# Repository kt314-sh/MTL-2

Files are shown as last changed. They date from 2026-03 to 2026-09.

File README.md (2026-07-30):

<div align="center">
<h1>📡 MTL-2: Portable High-Power LoRa node</h1>
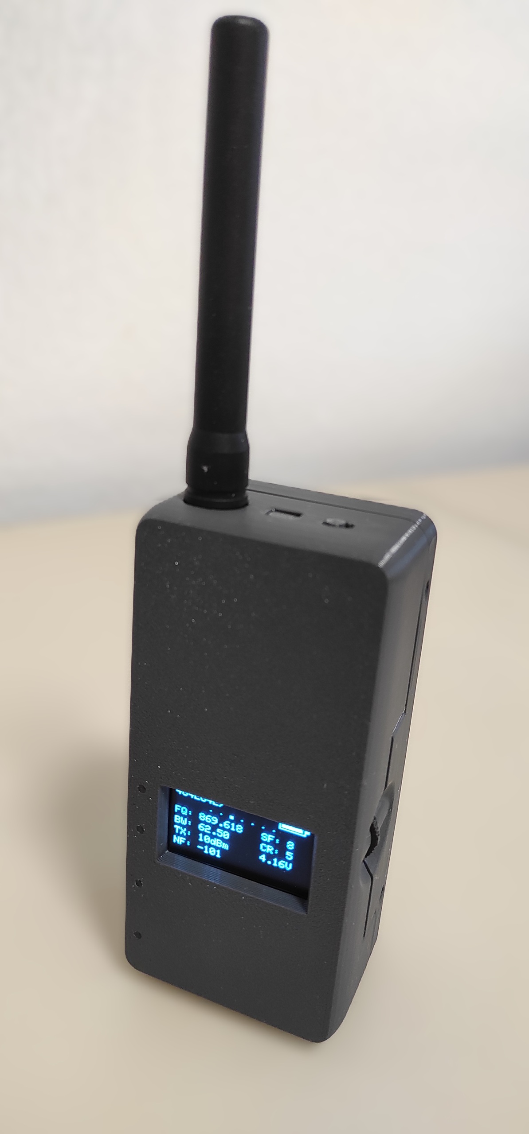
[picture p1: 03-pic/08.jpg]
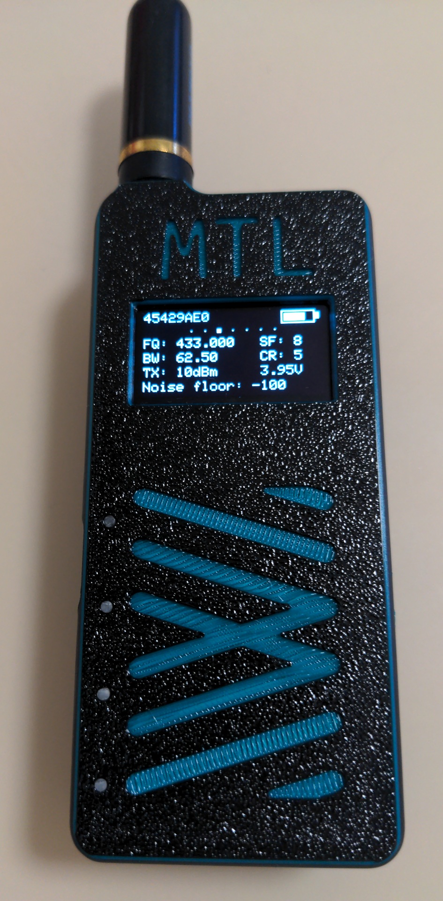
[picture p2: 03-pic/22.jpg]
   

<div align="left">
  
  ## MTL-2
MTL-2 - Это портативное энергоэкономичное устройство, основанное на модулях [Ebyete](https://www.ebyte.com/) и ProMicro (NRF52840). Предназначено для работы в [MeshCore](https://github.com/meshcore-dev), [Meshtastic](https://github.com/meshtastic), в качестве клиента и ретранслятора.

##  Ключевые особенности
* LoRa 30-31dBm
* Oled 1.3'
* Buzzer
* Switch Buzzer/Led (Quiet mode)
* Switch POWER set Low/Hight (20dBm/30dBm)
* Vibro-notification
* 3-position multifuctional switch or 3 button
* Connector for GPS-module like VK2828U7G5LF
* 1A Standalone Linear Li-Ion Battery Charger
* Battery protection lithium-ion/polymer battery
* Li-Ion cell holder 2x18650 TBH-18650-2A-P (FC1-5212)

##  Органы управления
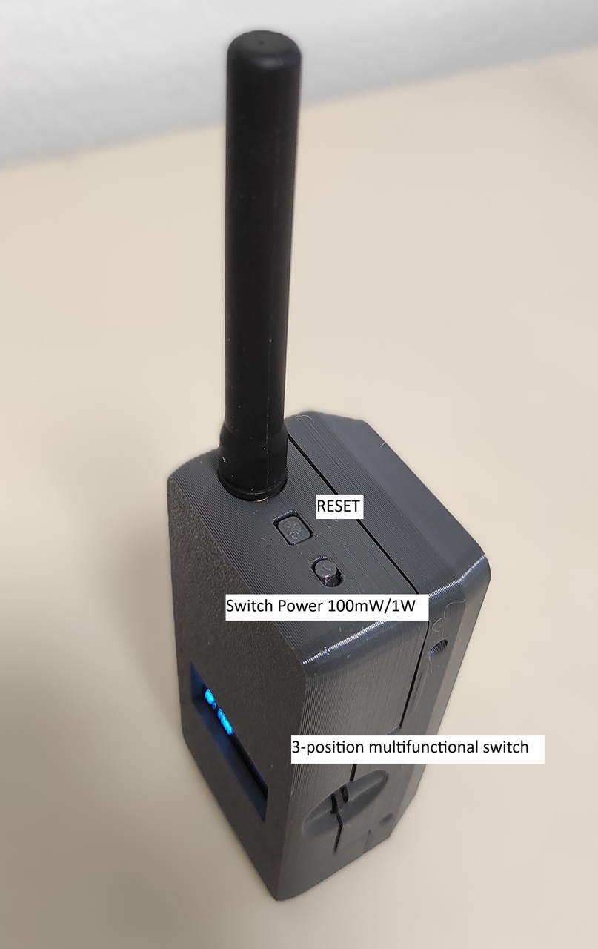
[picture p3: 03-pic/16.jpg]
interface1
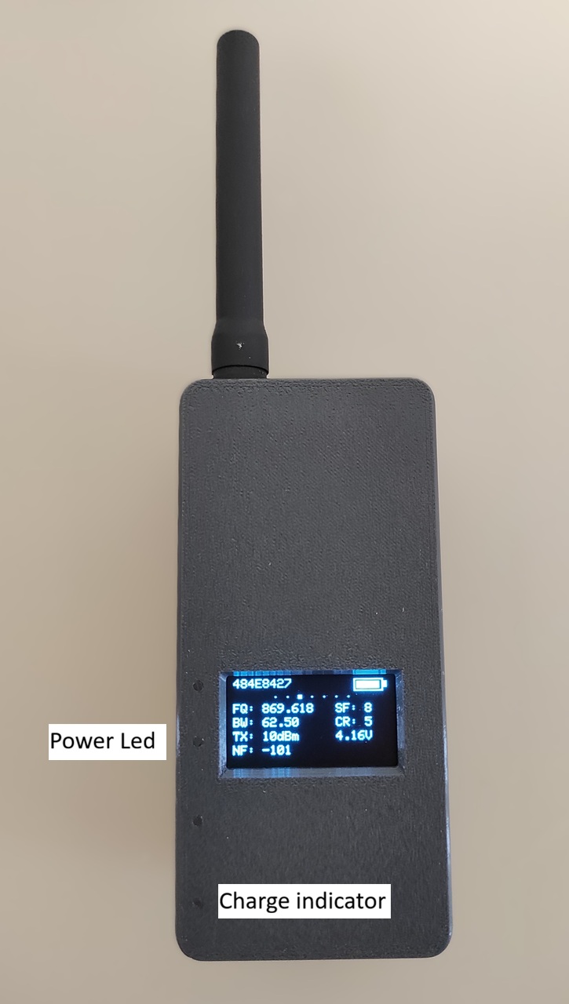
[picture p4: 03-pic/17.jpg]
interface2
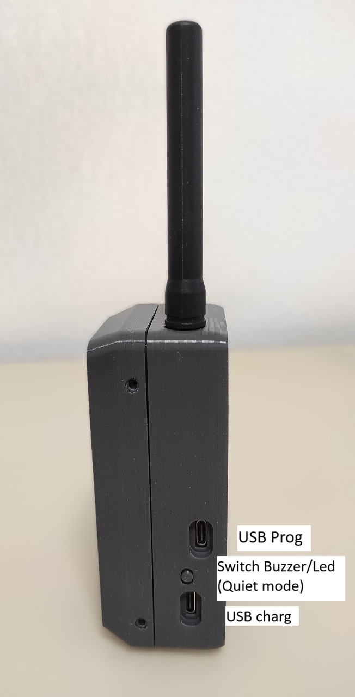
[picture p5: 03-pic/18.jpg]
interface3


##  Software MeshCore
The software was developed by [VladelfPv](https://github.com/VladelfPv)  [MTLmicro](https://github.com/VladelfPv/MeshCoreMTL.git) 

##  Software Meshtastic
Use the J9 jumper for compatibility with FakeTec. In this case, DC-DC Up remains constantly on, which will increase battery consumption to 10mA.

As a jumper, you can use the chip ferrite beads like BLM21PG221SN1D, BLM21PG121SH1D etc 
Оther settings are configured in the Meshtastic software.

GPIO: 
- 6-Buzzer.
- 8-Vibro.

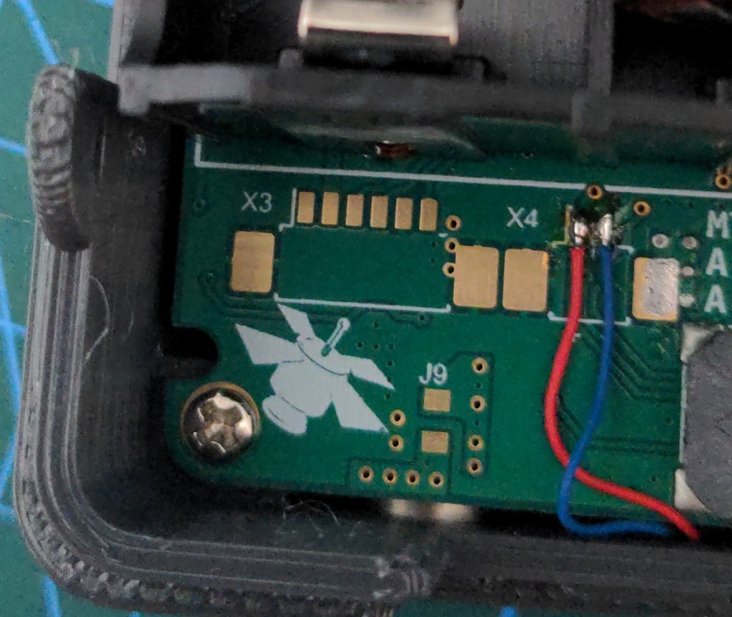
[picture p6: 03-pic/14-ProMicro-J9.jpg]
FakeTec
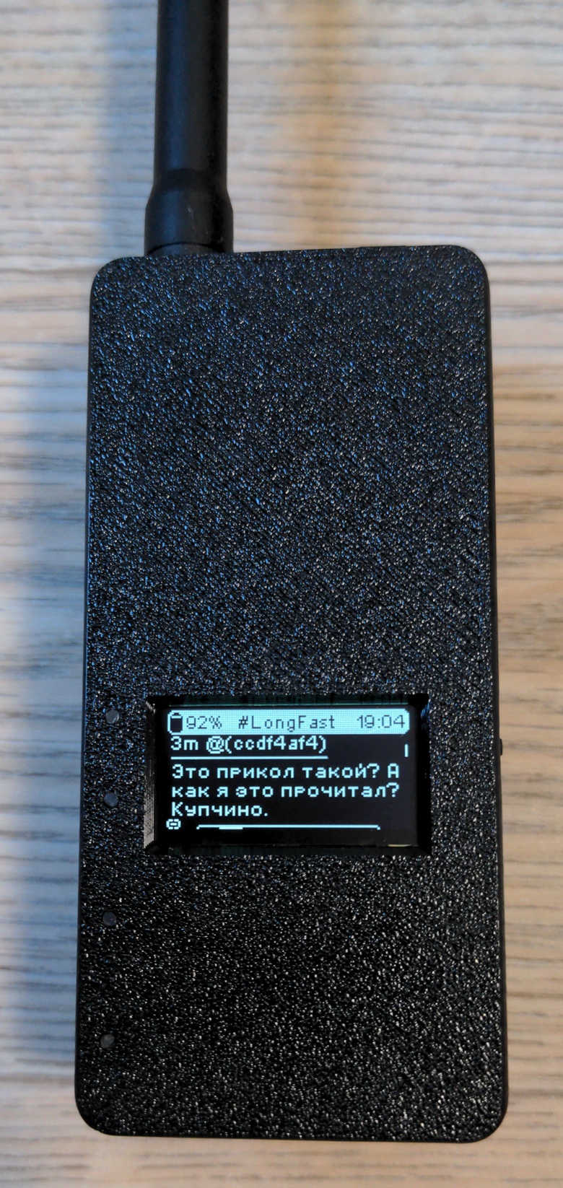
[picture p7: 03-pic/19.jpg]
FakeTec2


##  Update Software 
To update the Software, click the RESET button twice. In the window that opens, copy the firmware file xxxxx.uf2

interface1

### Frequency range
#### 150-170Mhz
- e22-170m30s    SX1268  30dBm

#### 430Mhz
- e22p-433m30s   SX1268          30dBm
- e22-400m30s    SX1262, SX1268  30dBm 
- e22-400m33s    SX1268          33dBm
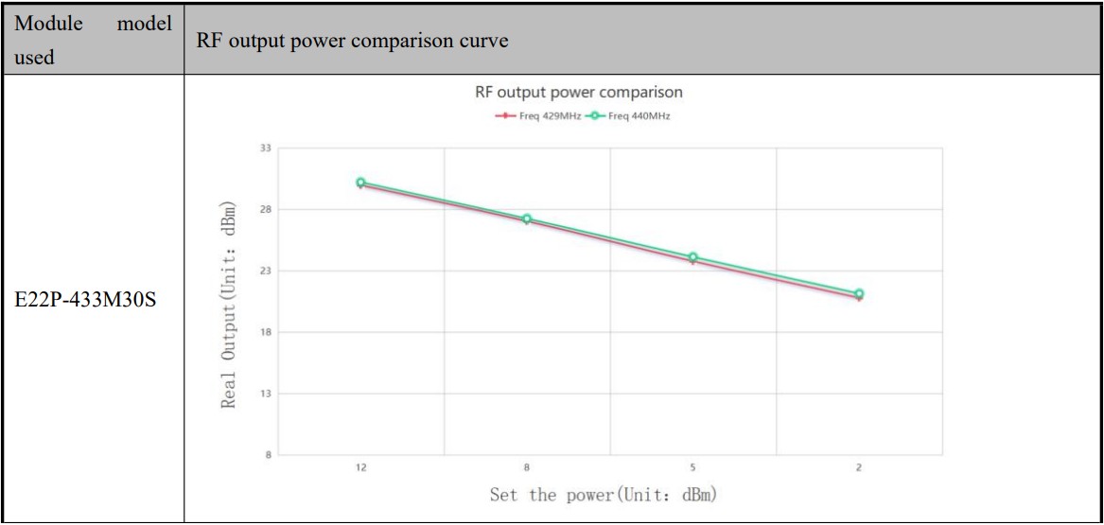
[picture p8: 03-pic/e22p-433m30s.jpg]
mtle22p433


#### 868-915Mhz
- e22p-868m30s   SX1262  31dBm
- e22p-915m30s   SX1262  31dBm 
- e22-900m30s    SX1262  30dBm
- e22-900m33s    SX1262  33dBm

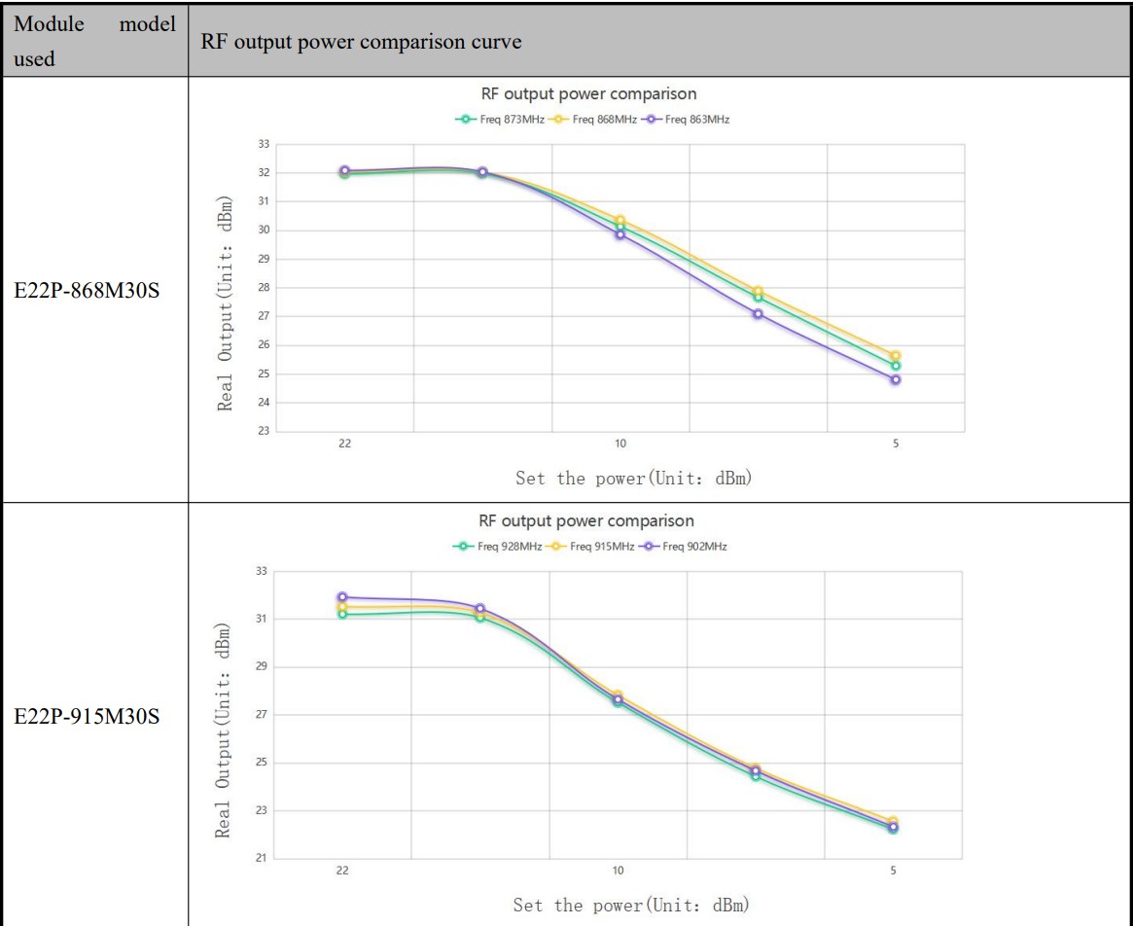
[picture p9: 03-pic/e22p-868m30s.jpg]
mtle22p868


##  Files
*[Gerber and Pick Place](/01-PCB/Fabrication)

*Shematic and documentation for [E22](/01-PCB/e22-C)

*Shematic and documentation for [E22p](/01-PCB/e22p-C)

*[IO spreadsheet](/01-PCB/MTL-2_IO.xlsx)

*3d model PCB [step](/04-3dmod)

*3d print model [Case](/05-case)

##  ⚠️Special attention
 Replace the capacitor C6 with a jumper!

##  Additional images

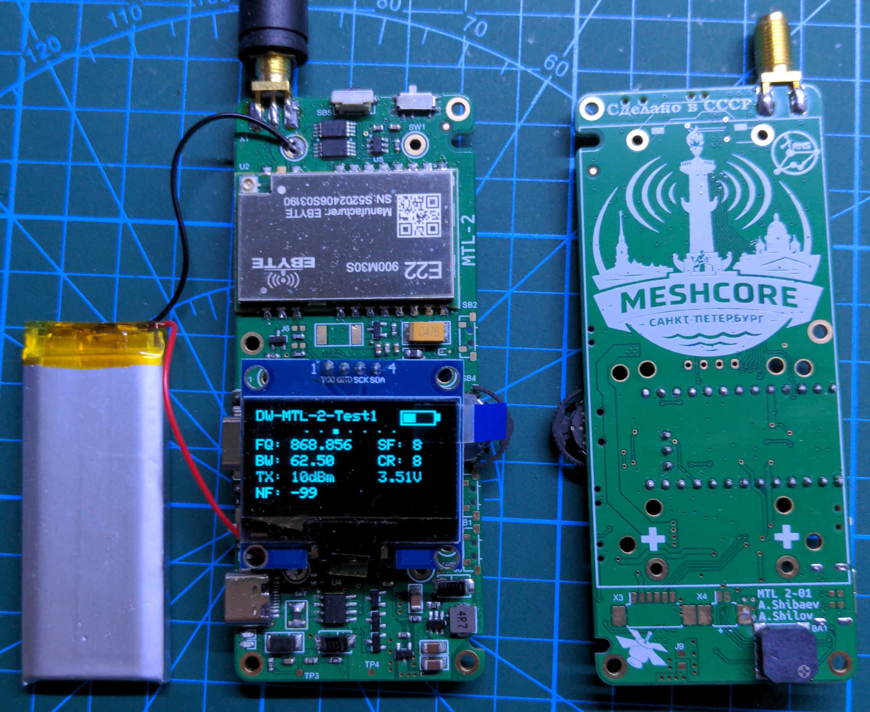
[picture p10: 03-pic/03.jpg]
Main
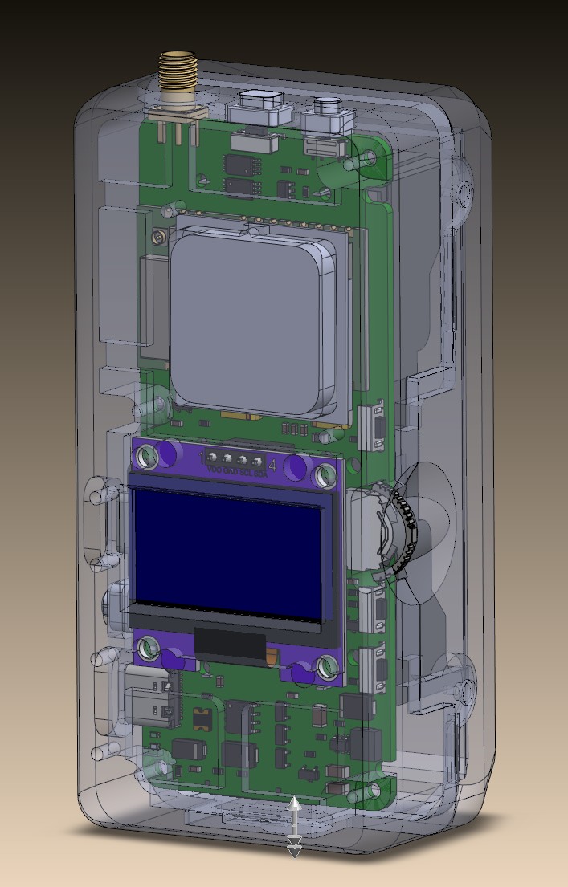
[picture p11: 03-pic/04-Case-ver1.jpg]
3dCaseF
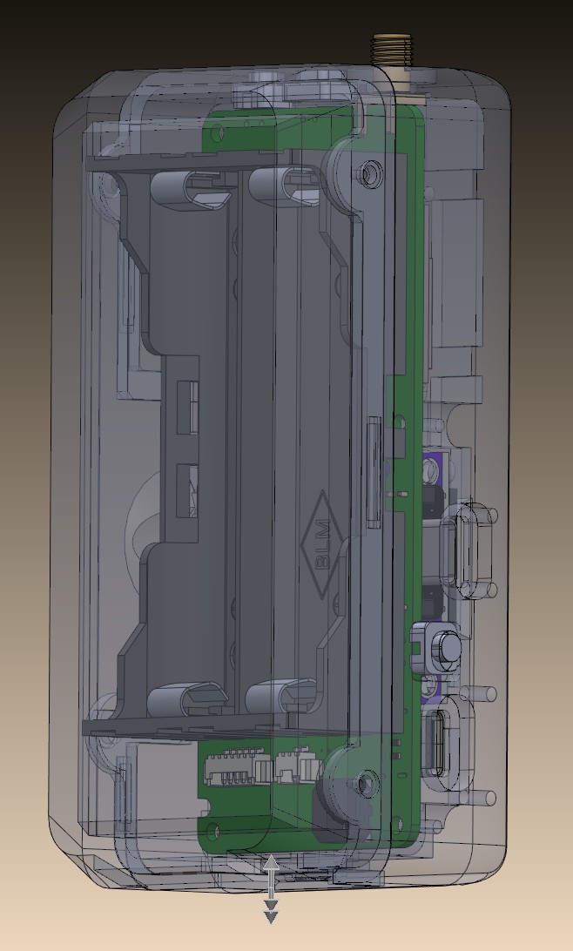
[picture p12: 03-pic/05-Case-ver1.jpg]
3dCaseB
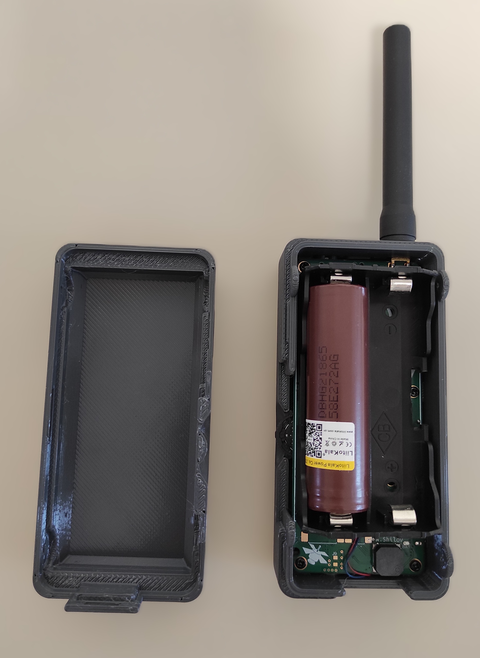
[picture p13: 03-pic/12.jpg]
back
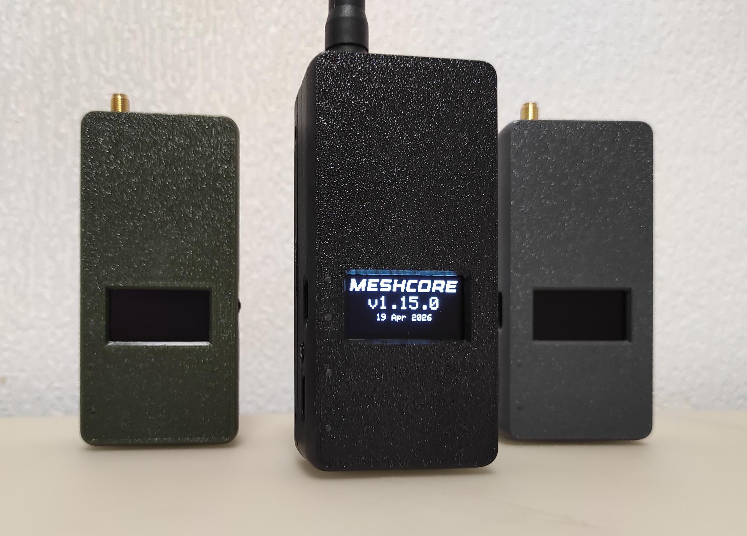
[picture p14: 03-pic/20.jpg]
case
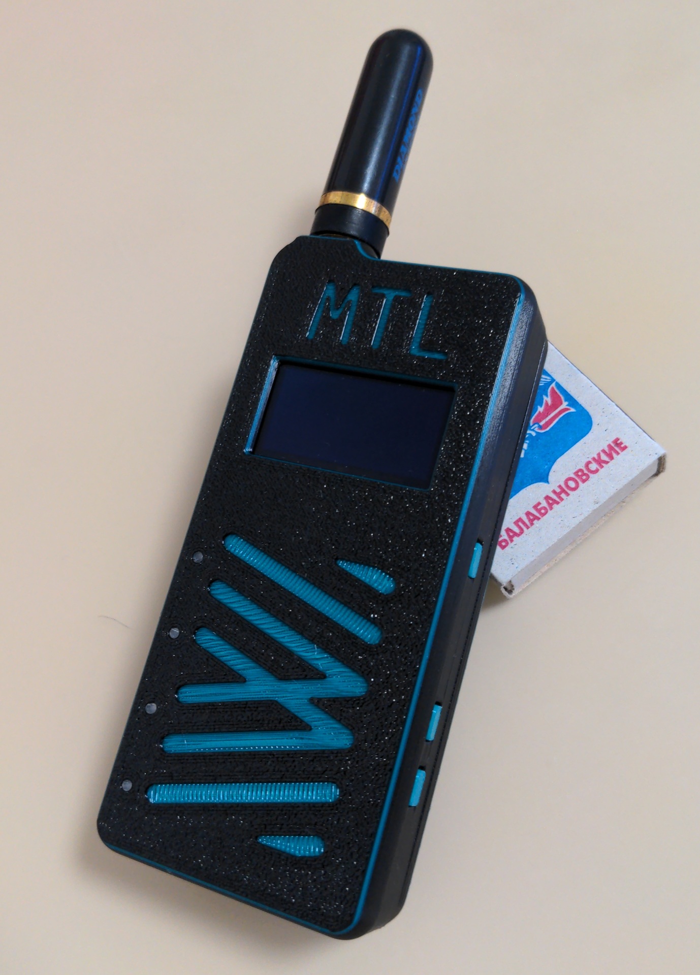
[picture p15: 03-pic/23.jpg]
 PCB

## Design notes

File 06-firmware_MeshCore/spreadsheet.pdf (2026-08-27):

| E22_sx1262_repeater.uf2
| E22_sx1262_SSD1306_repeater.uf2
E22p_sx1268_repeater.uf2
E22p_sx1268_SSD1306_repeater.uf2
| Файл прош+вк+ | Модуль LoRa | Д+сплей
SX1262 | SX1268 | Oled 1.3' | Oled 0.96'
E22-900m30s, E22-400m30s, E22-170m30s | E22p-868m30s, E22p-915m30s | E22-400m33s, E22-170m30s | E22p-430m30s, | SH1106 | SSD1306
| E22_sx1262_companion_radio_usb.uf2
| E22_sx1262_companion_radio_ble.uf2
| E22_sx1262_SSD1306_companion_radio_ble.uf2
| E22p_sx1268_companion_radio_usb.uf2
| E22p_sx1268_companion_radio_ble.uf2
| E22p_sx1268_SSD1306_companion_radio_usb.uf2
| E22p_sx1268_SSD1306_companion_radio_ble.uf2

Реп+тер,

мост UART

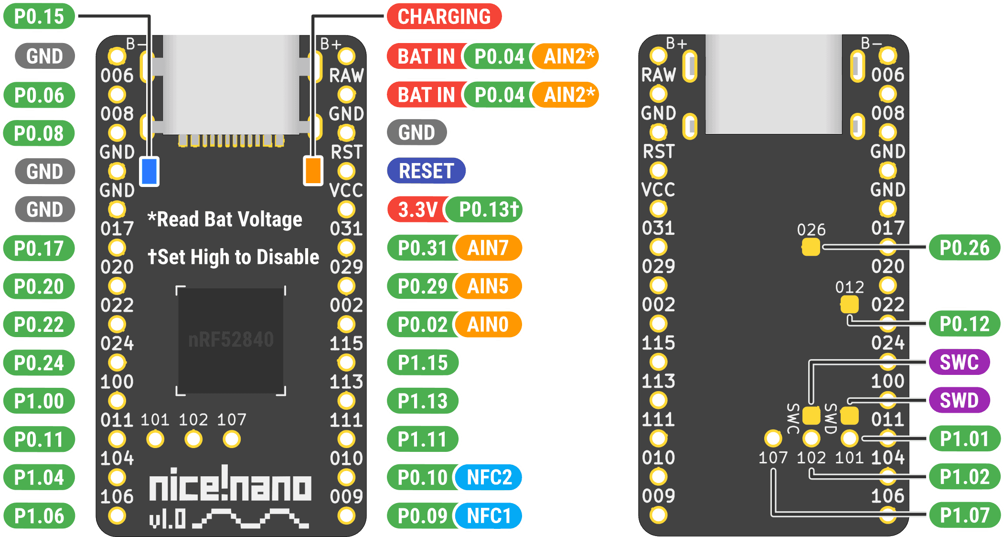
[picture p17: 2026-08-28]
02-datasheet/NiceNano_v1_pinout.png

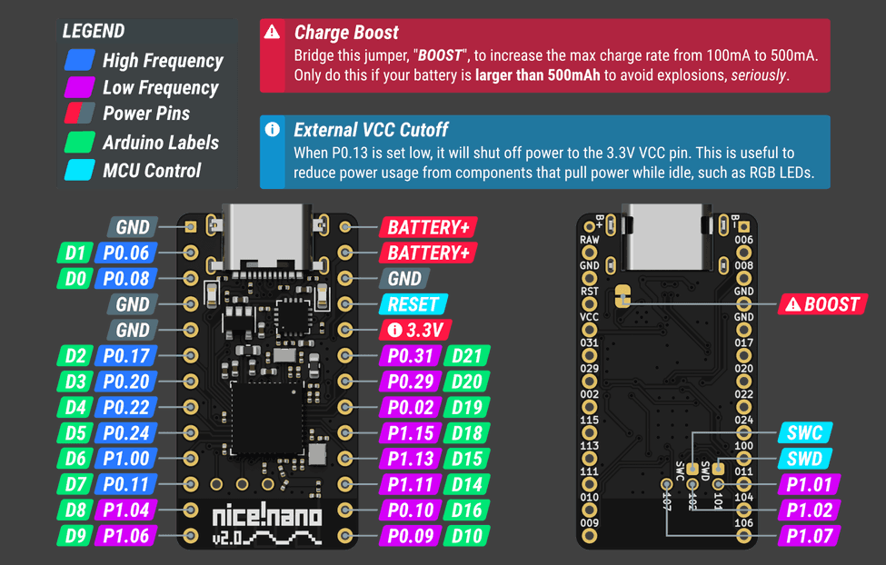
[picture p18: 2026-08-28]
02-datasheet/NiceNano_v2_pinout.png

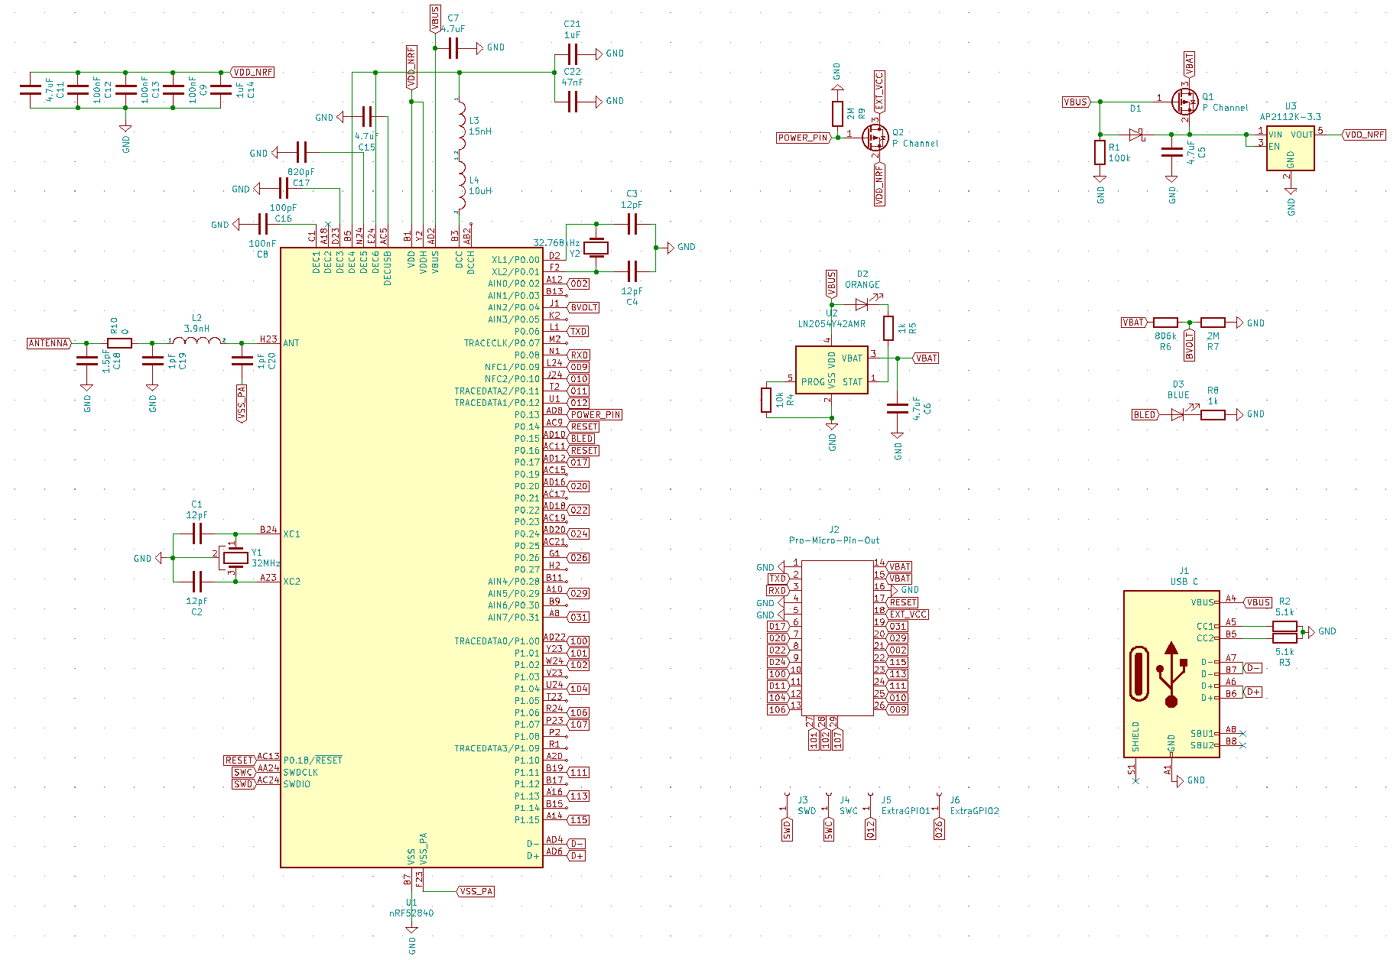
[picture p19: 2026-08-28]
02-datasheet/NiceNano_v1_schematic.png

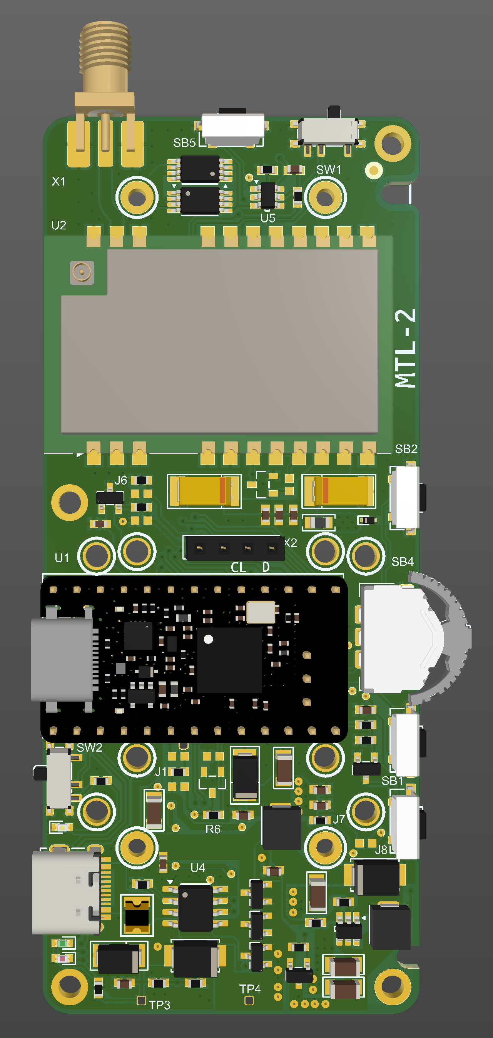
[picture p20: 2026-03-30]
03-pic/e22p-1.png

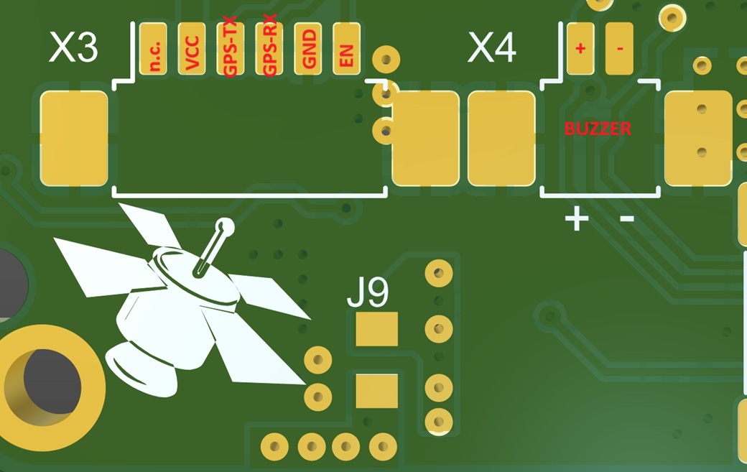
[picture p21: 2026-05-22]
03-pic/21-UART.jpg

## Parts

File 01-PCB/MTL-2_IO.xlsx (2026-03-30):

Port | GPIO | D Arduino | Net |  | Описание
P0.02 | 15 | 19 | MISO |  | LoRA
P0.06 | 0 | 1 | DO_BUZZ | PWM | Пассивный Зуммер EN=H
P0.08 | 1 | 0 | DO_VIBR | DO | Вибромотор, EN=H
P0.09 | 10 | 10 | NRST |  | LoRA
P0.10 | 11 | 16 | DIO1 |  | LoRA
P0.11 | 7 | 7 | i2c_SCL | I2C | Oled
P0.13 | 21 |  |  | DO | Включить питание 3.3В (дисплей, GPS, вибро) (нет необходимости отключать???)
P0.15 | 22 | 13 |  | DO | Led Красный
P0.17 | 2 | 2 | RX_EN | DO | Резерв, не используем, Модуль E22 активируем RX, Модуль E22p пробуждаем модуль (см. Datasheet)
P0.20 | 3 | 3 | GPS_RX | UART | Для GPS приемника VK2828U7G5LF
P0.22 | 4 | 4 | GPS_TX | UART | Для GPS приемника VK2828U7G5LF
P0.24 | 5 | 5 | GPS_EN | DO | Для GPS приемника пробуждение H, EN=H
P0.29 | 16 | 20 | BUSY |  | LoRA
P0.31 | 17 | 21 | ADC | AI | Измерение напряжения АКБ, коэффициент 1.47 (делитель 1МОм/680к)
P1.00 | 6 | 6 | SET_S | DI | Кнопка центральная, основная. Pull UP
P1.01 | 18 |  | SET_A | DI | Кнопка вверх. Pull UP
P1.02 | 19 |  | SET_B | DI | Кнопка вниз. Pull UP
P1.04 | 8 | 8 | i2c_SDA | I2C | Oled 1306
P1.06 | 9 | 9 | DC_EN | DO | Включить питание 5В. Модуль LoRa, GPS. EN=H
P1.07 | 20 |  | SET_PVR | DI | Переключатель ползунковый, для переключения мощности L/H. Например 20dBm/30dBm, либо одно значение берётся из переменной настроек приложения, второе максимальное значение (в настройках для модуля E22 20dBm=30dBm на выходе)
P1.11 | 12 | 14 | SCK |  | LoRA
P1.13 | 13 | 15 | NSS |  | LoRA
P1.15 | 14 | 18 | MOSI |  | LoRA

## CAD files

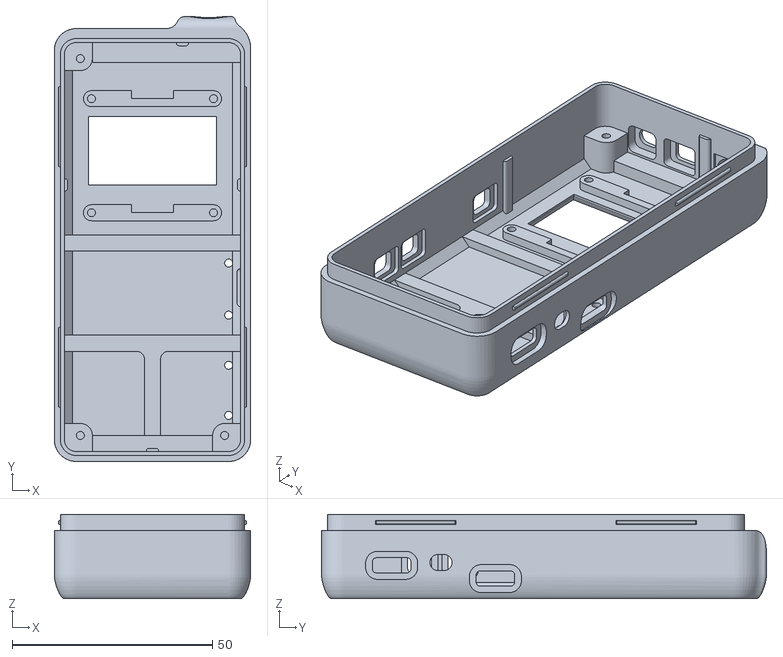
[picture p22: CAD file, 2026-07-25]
05-case/ver2/3d-Print/main21.07.2026.STL
49.0 x 111.0 x 21.0

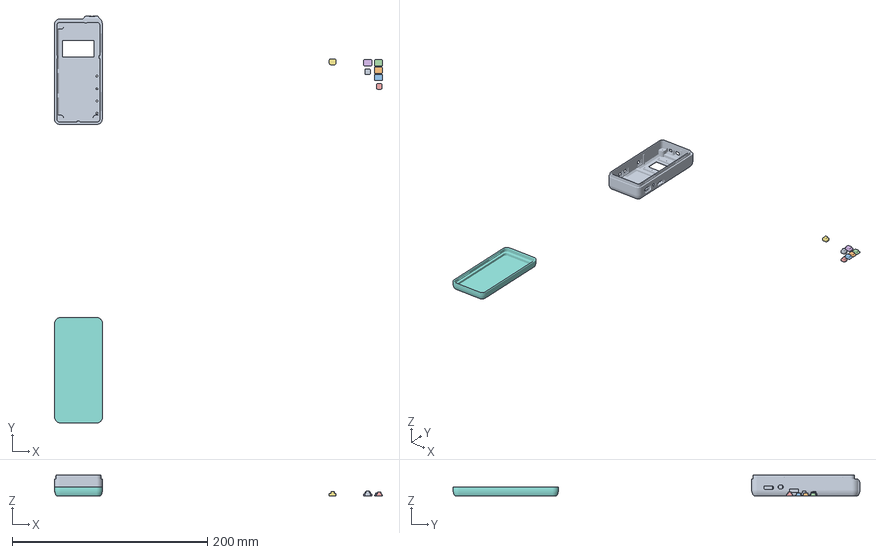
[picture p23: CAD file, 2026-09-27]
05-case/ver2/3d-Print/MTL-2v2.3mf
336.0 x 416.7 x 21.0 mm
main21.07.2026.STL
BT2-L.STL x 3
SW2.STL
BT1-L.STL
SW1.STL
Back-104060.STL
SW1-2.STL

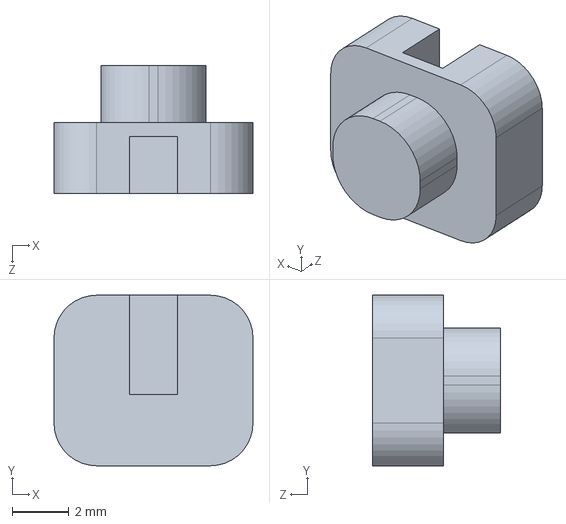
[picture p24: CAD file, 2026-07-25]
05-case/ver2/SolidWork/SW1.SLDPRT
7.00 x 6.00 x 4.50 mm

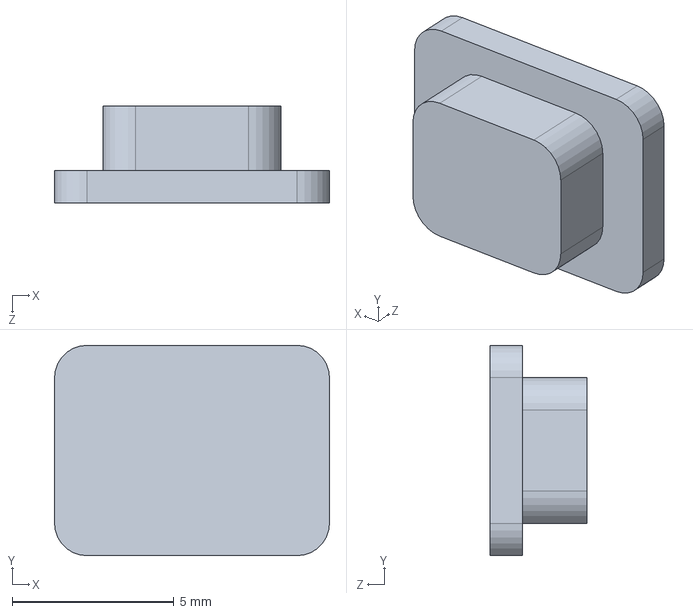
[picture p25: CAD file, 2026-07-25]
05-case/ver2/SolidWork/BT2-L.SLDPRT
8.50 x 6.50 x 3.00 mm

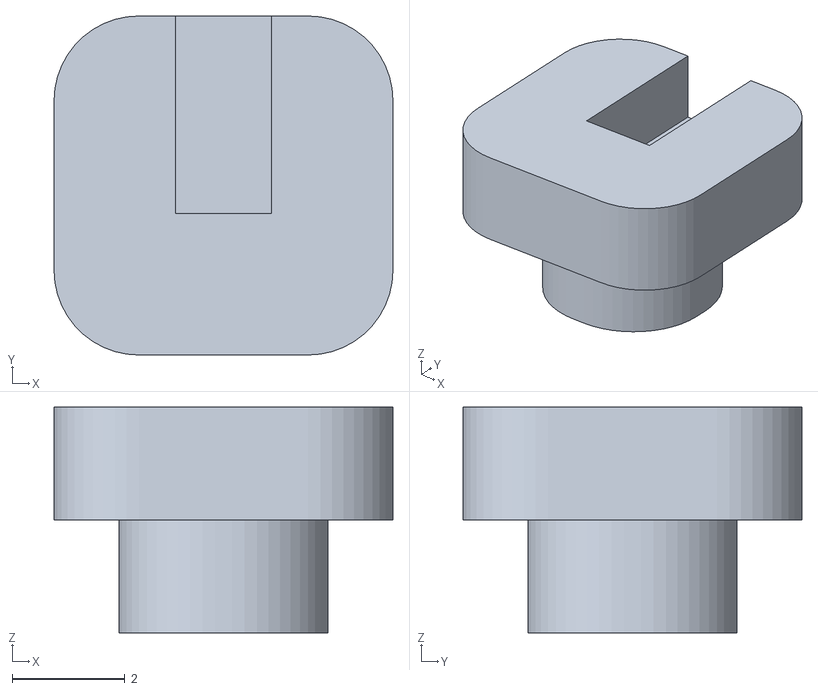
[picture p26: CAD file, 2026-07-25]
05-case/ver2/3d-Print/SW2.STL
6.00 x 6.00 x 4.00

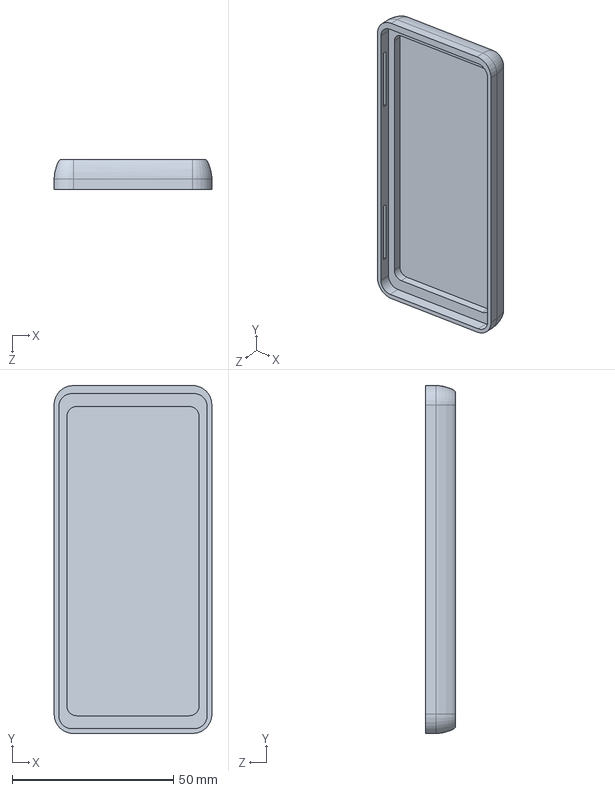
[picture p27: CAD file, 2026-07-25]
05-case/ver2/SolidWork/back1.SLDPRT
49.0 x 108.0 x 9.20 mm

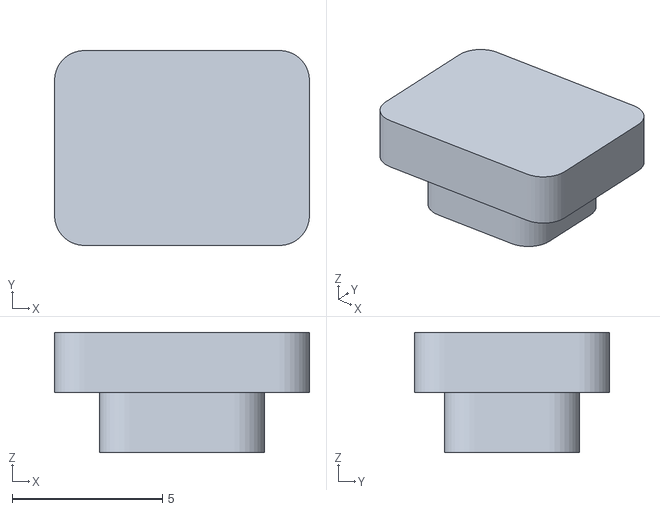
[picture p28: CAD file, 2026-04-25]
05-case/ver2/3d-Print/BT1-L.STL
8.50 x 6.50 x 4.00

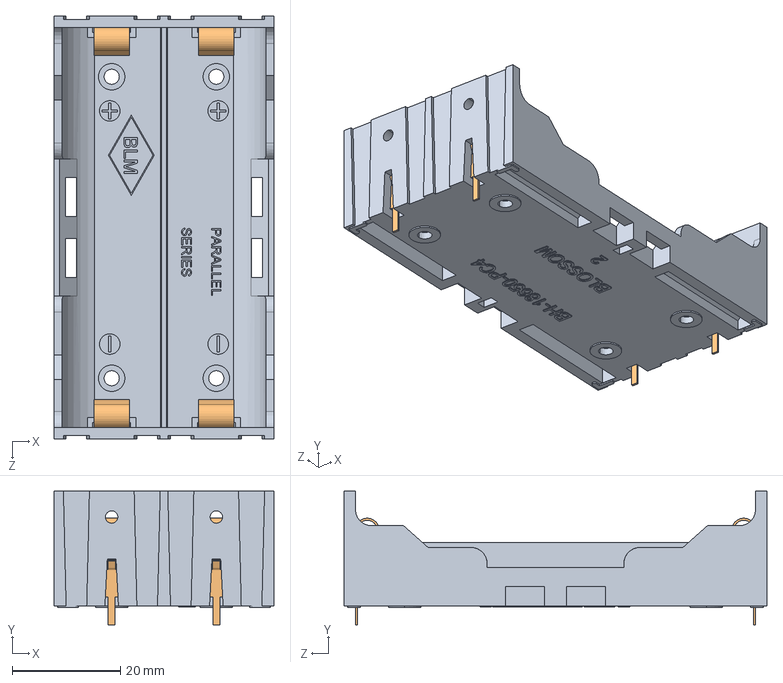
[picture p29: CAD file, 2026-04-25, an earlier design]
05-case/ver1/SolidWork/BC-18650-PC4.SLDASM
40.5 x 24.7 x 78.0 mm
____________2^__________ ____________________________ BC-18650-PC4_____ __________________.STEP.STEP
____________3^__________ ____________________________ BC-18650-PC4_____ __________________.STEP.STEP x 4

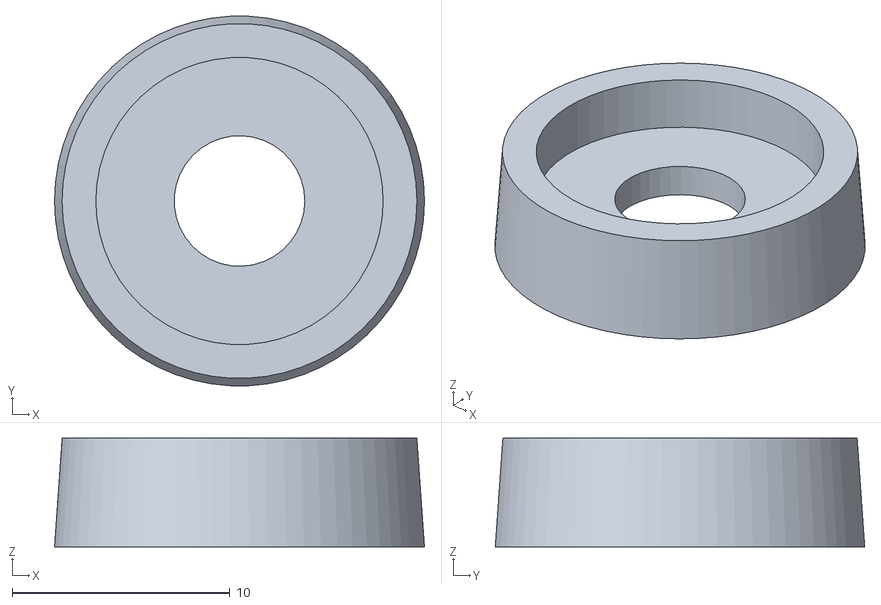
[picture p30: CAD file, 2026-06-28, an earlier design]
05-case/ver1/3d-Print/Ant-Holder/SONGKL-868.STL
17.0 x 17.0 x 5.00

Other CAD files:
05-case/ver2/SolidWork/main21.07.2026cp.SLDPRT
05-case/ver2/SolidWork/SW2.SLDPRT
05-case/ver2/3d-Print/BT2-L.STL
05-case/ver2/3d-Print/SW1.STL
05-case/ver2/3d-Print/Back-104060.STL
05-case/ver2/SolidWork/BT1-L.SLDPRT
05-case/ver2/SolidWork/18650.SLDPRT
05-case/ver2/3d-Print/18650.STL
05-case/ver2/SolidWork/104060.SLDPRT
05-case/ver1/3d-Print/Ant-Holder/All_TPU-95.3mf
05-case/ver1/3d-Print/Ant-Holder/GIZONT_GT-7702-20.STL
05-case/ver1/3d-Print/Ant-Holder/GIZONT_LORA-868.STL
05-case/ver1/3d-Print/Ant-Holder/RE-771.STL
05-case/ver1/3d-Print/Ant-Holder/TYT_TH-UV99.STL
05-case/ver1/3d-Print/BT1-L.3mf
05-case/ver1/3d-Print/Back.3mf
05-case/ver1/3d-Print/Back.STL
05-case/ver1/3d-Print/Bat-1.3mf
05-case/ver1/3d-Print/Bat-1.STL
05-case/ver1/3d-Print/Middle.3mf
05-case/ver1/3d-Print/Middle.STL
05-case/ver1/3d-Print/SW1-2.3mf
05-case/ver1/3d-Print/SW1-2.STL
05-case/ver1/3d-Print/SW1-3.3mf
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

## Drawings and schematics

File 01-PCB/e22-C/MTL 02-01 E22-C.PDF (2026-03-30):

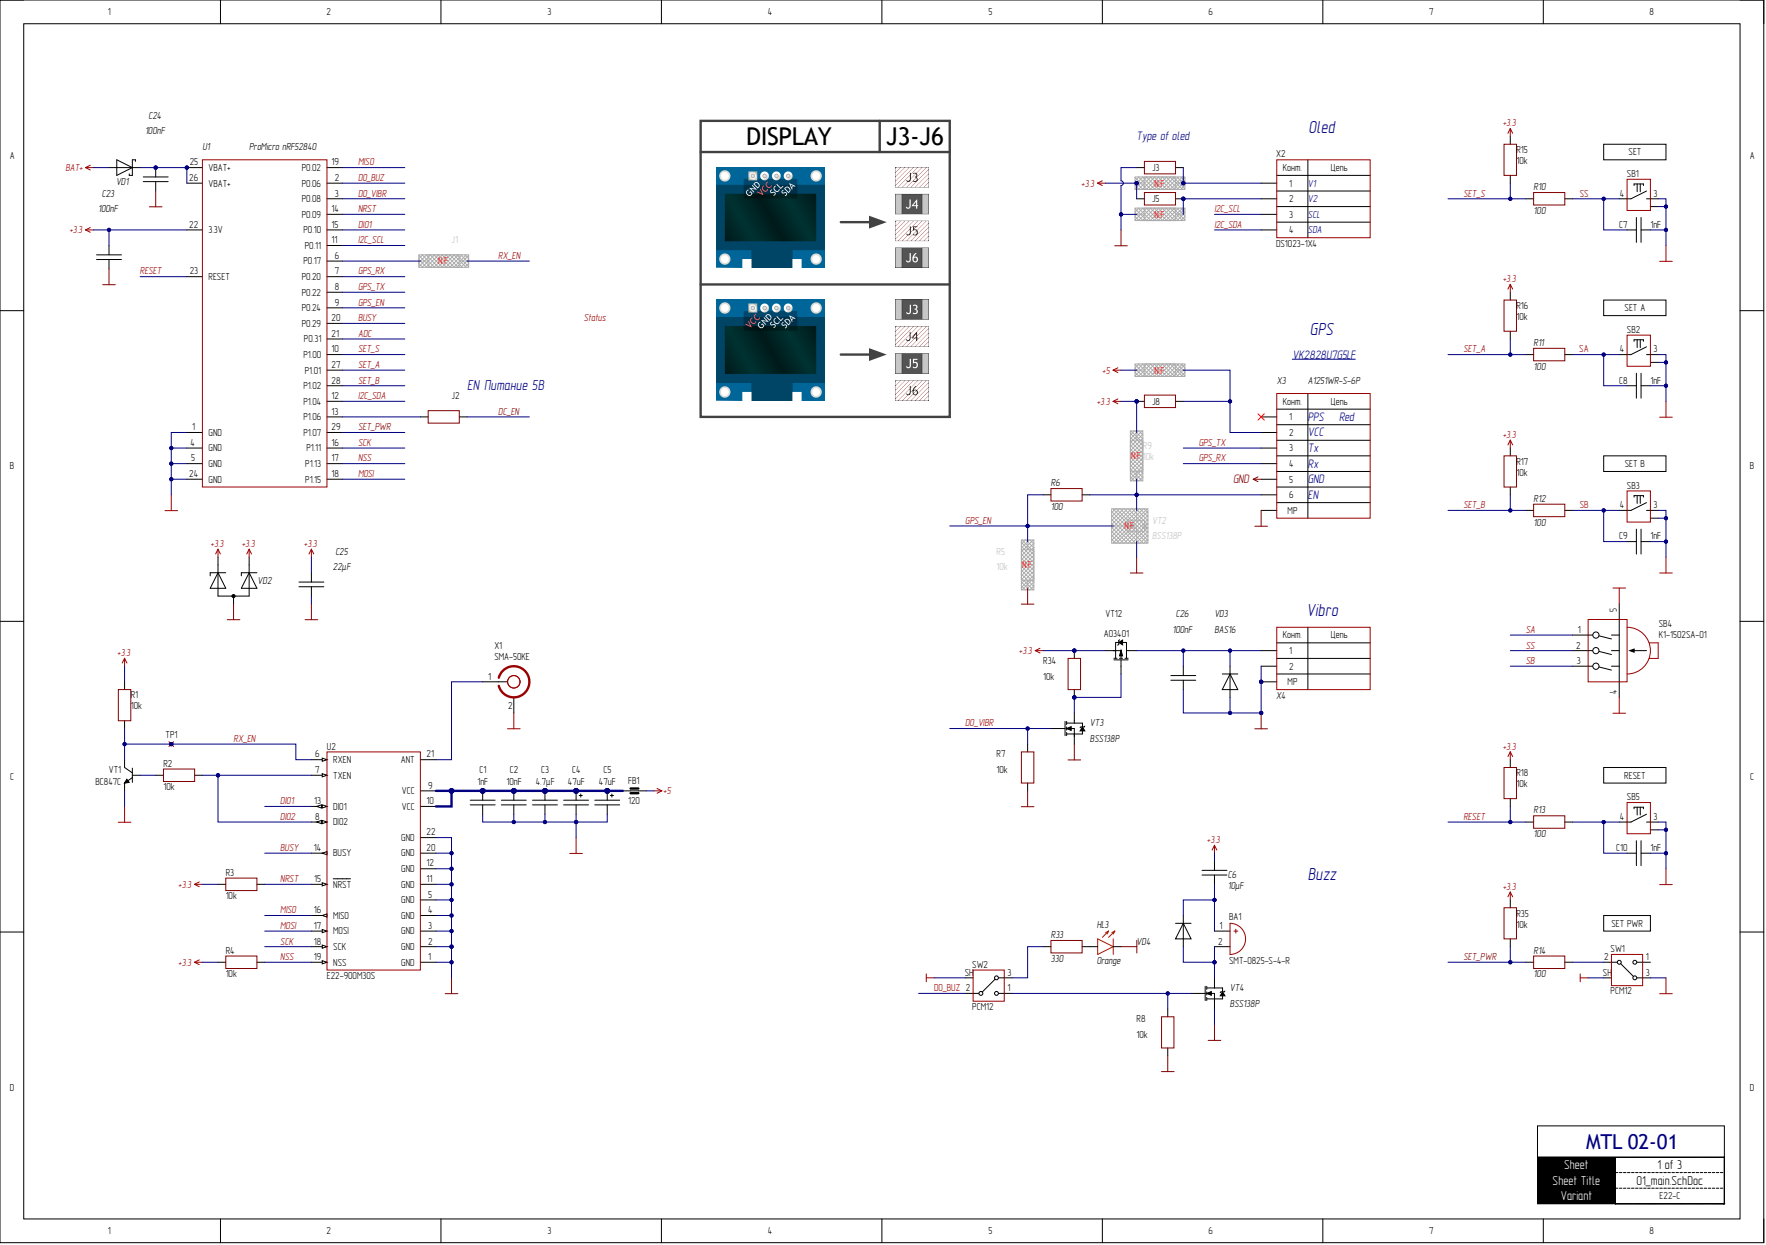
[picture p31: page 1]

J6N.F. | 3 | SCL

4 | SDA

1 | PPS Red
2 | VCC

5 | GND
6 | EN
MP

Конт. | Цепь

Sheet | 1 of 3
Sheet Title | 01_main.SchDoc
Variant | E22-C

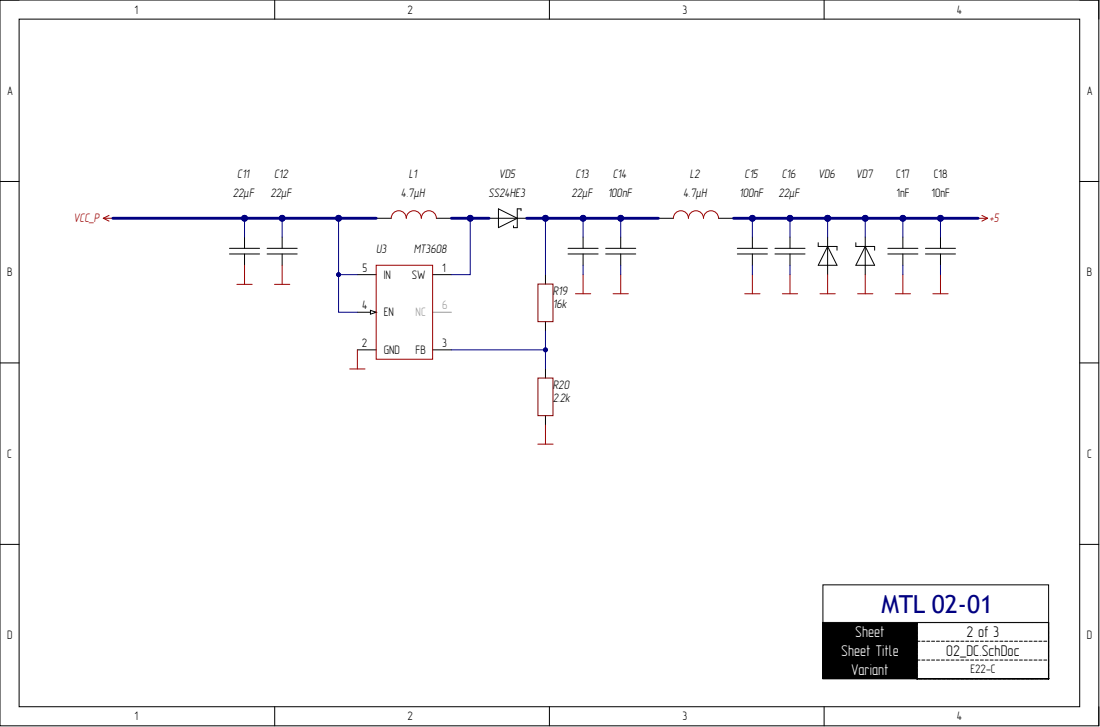
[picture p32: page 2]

Sheet | 2 of 3
Sheet Title | 02_DC.SchDoc
Variant

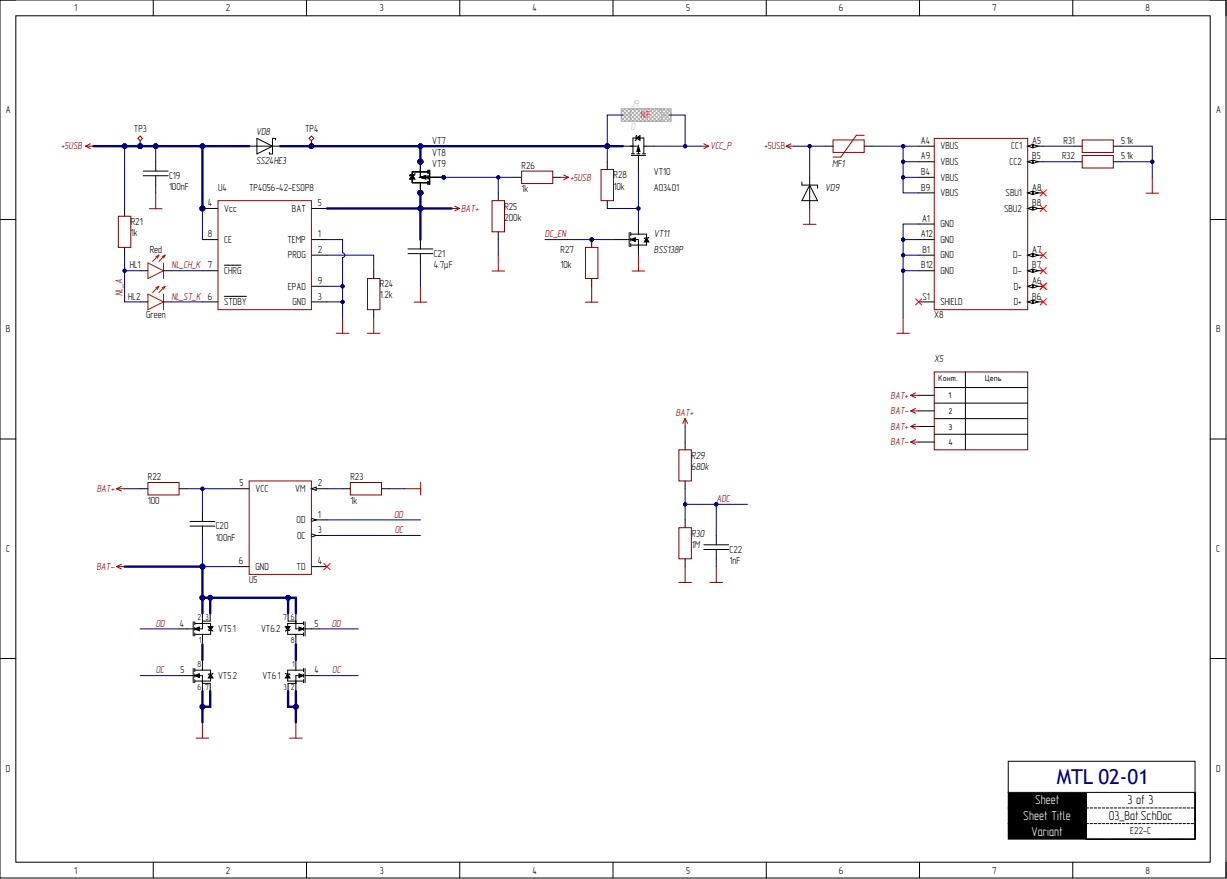
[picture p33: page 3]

VBUS A9
VBUS B4

Конт. | Цепь

Sheet | 3 of 3
Sheet Title | 03_Bat.SchDoc
Variant

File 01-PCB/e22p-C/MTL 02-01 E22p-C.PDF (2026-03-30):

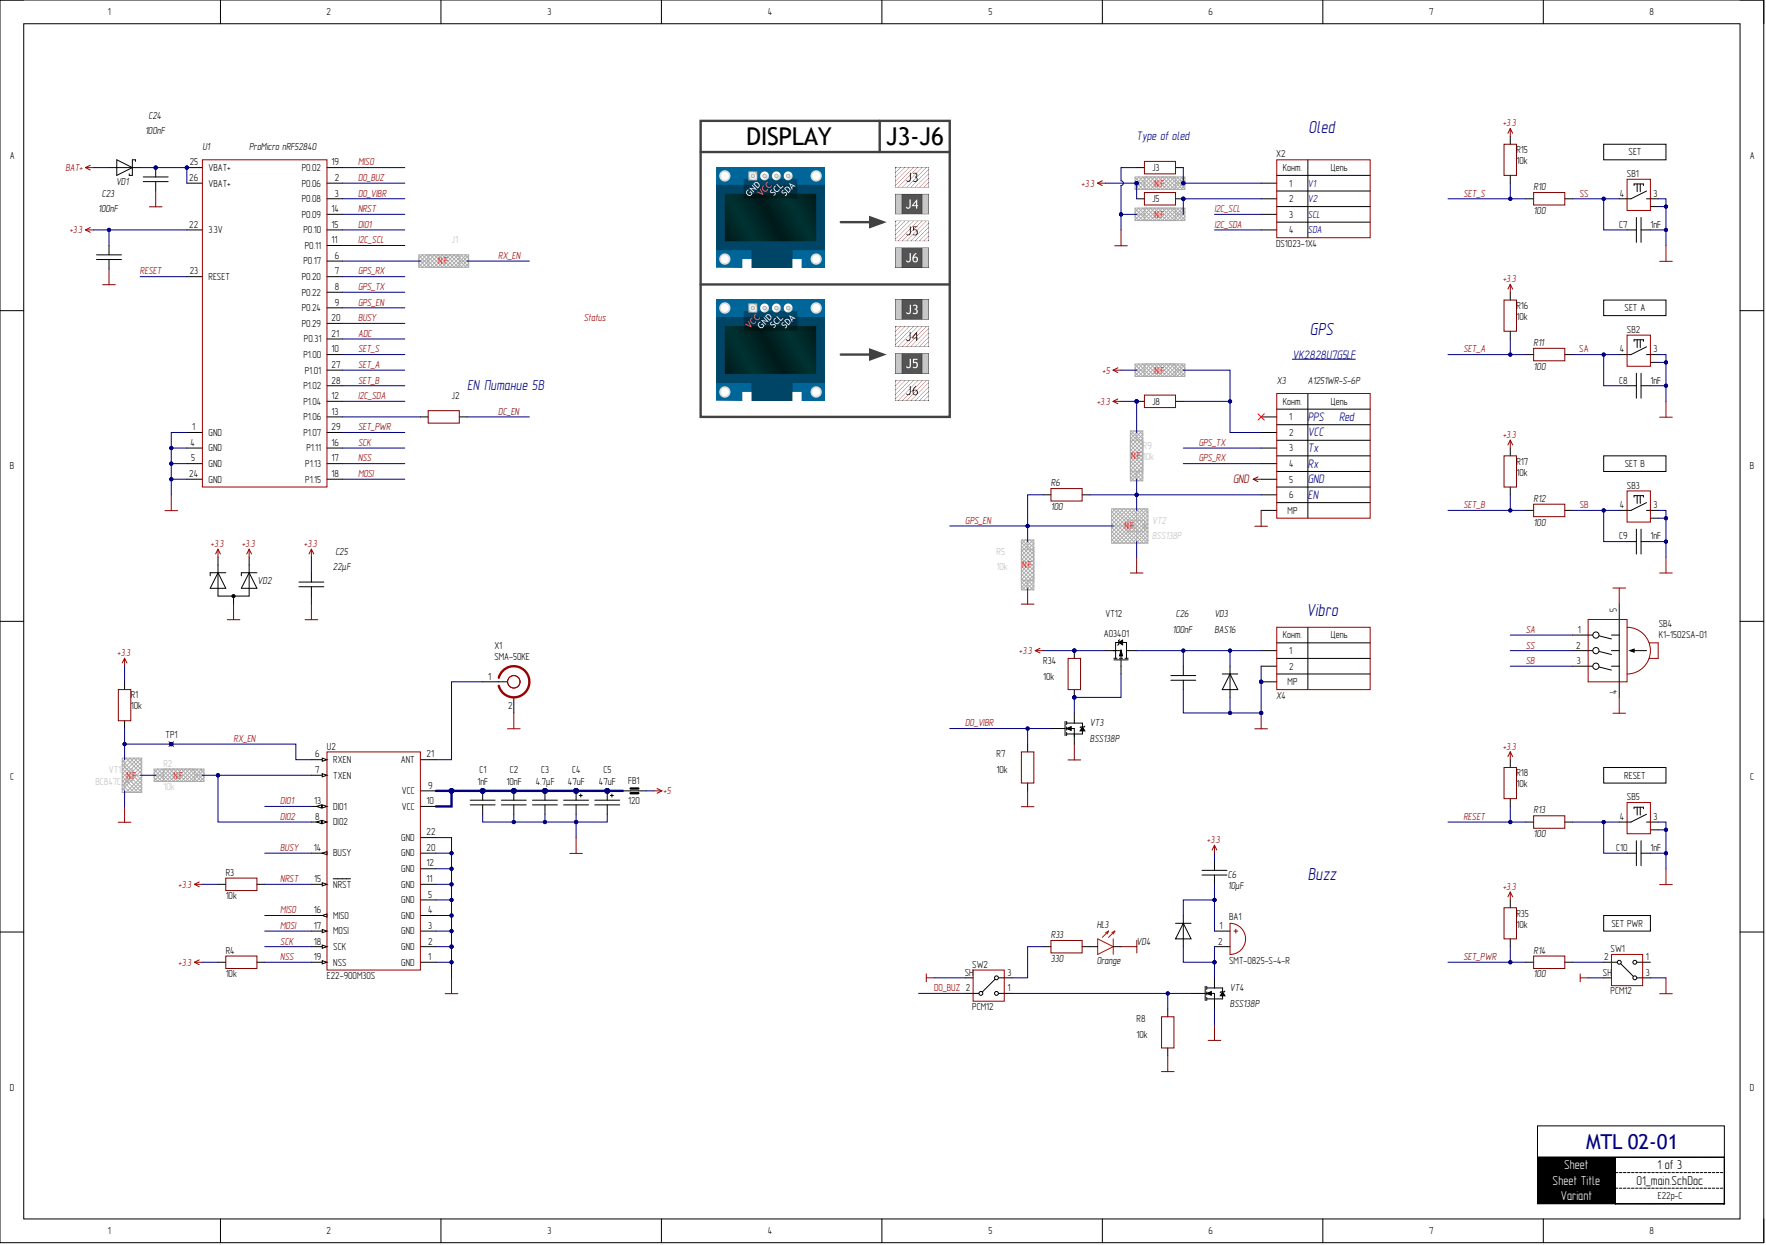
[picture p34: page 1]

J6N.F. | 3 | SCL

4 | SDA

1 | PPS Red
2 | VCC

5 | GND
6 | EN
MP

Конт. | Цепь

Sheet | 1 of 3
Sheet Title | 01_main.SchDoc
Variant | E22p-C

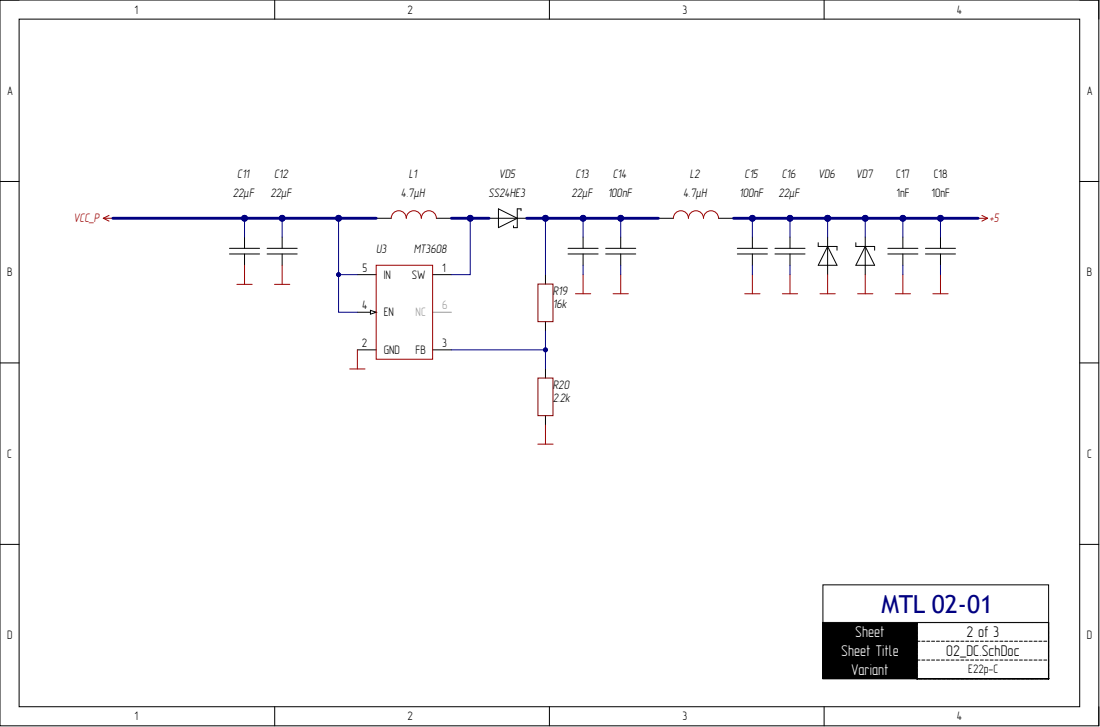
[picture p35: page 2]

Sheet | 2 of 3
Sheet Title | 02_DC.SchDoc
Variant

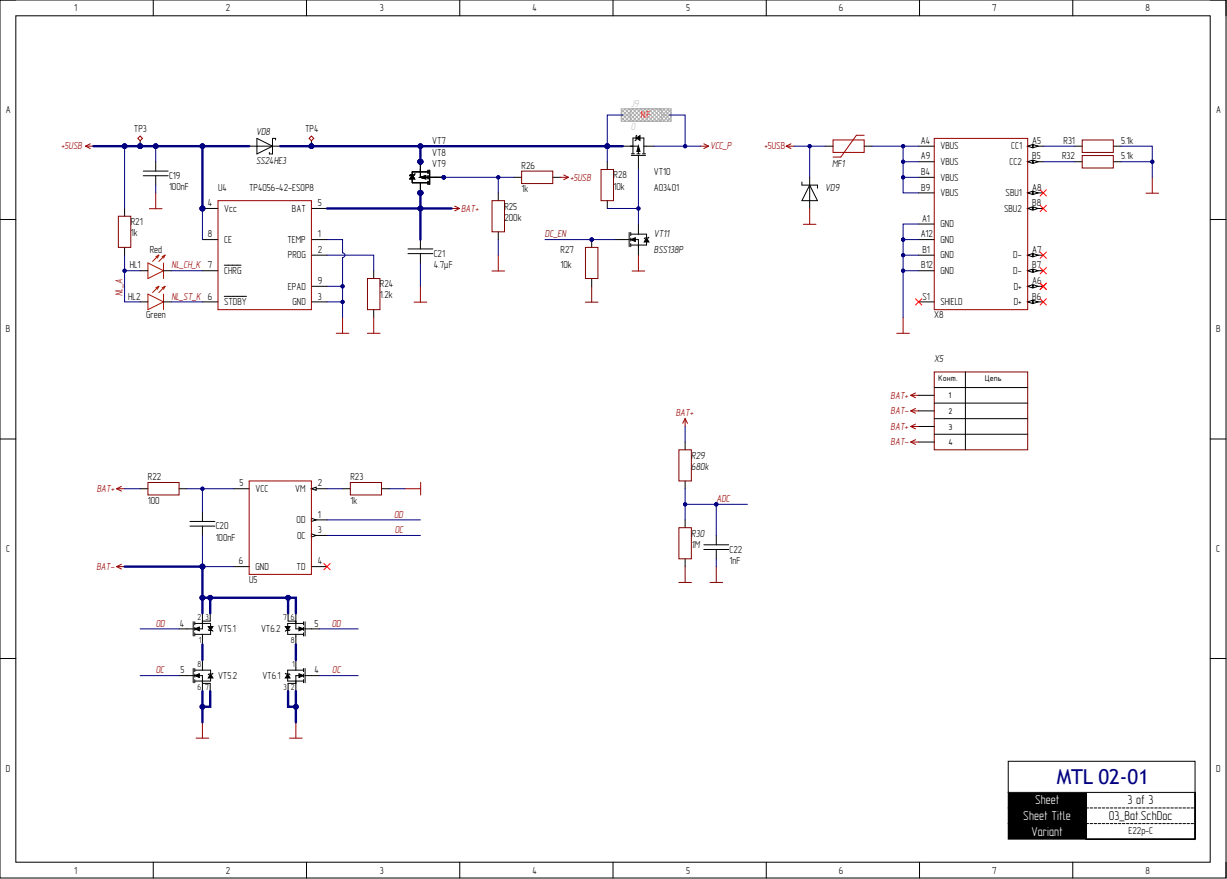
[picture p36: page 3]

VBUS A9
VBUS B4

Конт. | Цепь

Sheet | 3 of 3
Sheet Title | 03_Bat.SchDoc
Variant

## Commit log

2026-04-25 Добавлен корпус
    [BC-18650-PC4.SLDASM, BT1-L.3mf, BT1-L.SLDPRT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]
2026-04-25 Обновил корпус
    Откорректирован зазор манипулятора
    [Middle.SLDPRT, Middle.STL]
2026-04-26 refresh 3d model switch
    [Middle.3mf, SW1-2.3mf, SW1-2.SLDPRT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]
2026-04-26 GERBER and PP
    Добавил файлы GERBER и Peak and Place
    [Pick Place for MTL-1v2-b.csv, Pick Place for MTL-1v2-t.csv, Pick Place for e22.csv]
2026-04-28 Update README.md
    Дополнил описание для Meshtastic
2026-04-28 Update README.md
    Откорректировал отображение фото в описании
2026-04-28 add J9
    Фото перемычки J9
2026-05-02 add firmfare meshcore
    companion 1.15.0
    [SW1-2.3mf]
2026-05-22 add UART
    UART con discr
2026-06-28 add antenna holder
    [All_TPU-95.3mf, GIZONT_GT-7702-20.SLDPRT, GIZONT_GT-7702-20.STL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]
2026-07-25 add case MTL-2 ver2
    [104060.SLDPRT, BT1-L.SLDPRT, BT1-L.STL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]
2026-07-26 add pic new case
    [MTL-2v2.3mf]
2026-07-26 add 185650
    [18650.SLDPRT, 18650.STL]
2026-08-27 add spreadsheet
    [spreadsheet.xlsx]
2026-08-28 add 1.17.1
    invert GPS EN, Power Enable: high level means the module works, low level means
    the modules is closed
2026-10-31 Исправлен корпус
